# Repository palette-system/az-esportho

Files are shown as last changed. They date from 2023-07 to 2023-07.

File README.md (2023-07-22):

# AZ-ESPortho

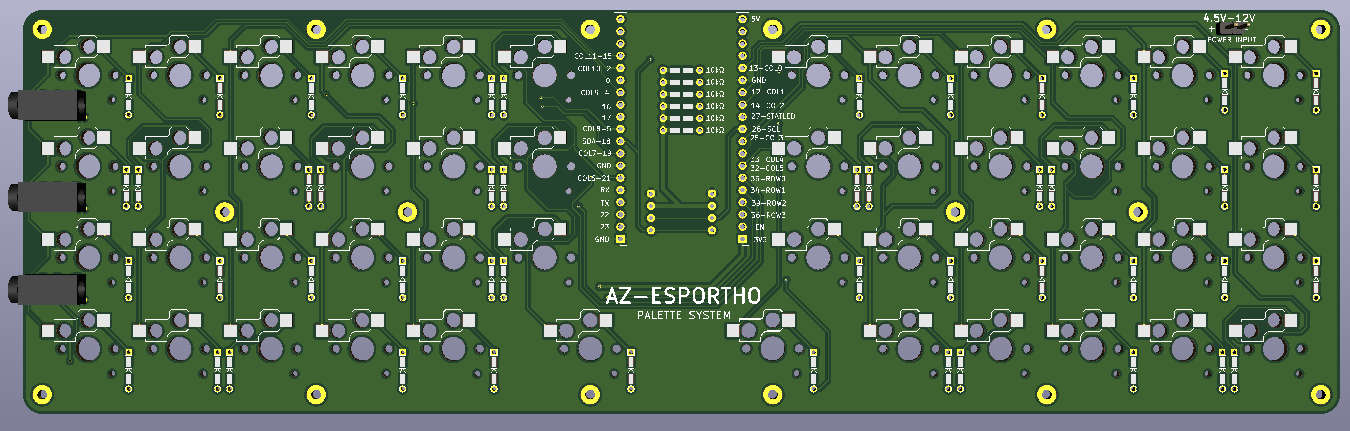
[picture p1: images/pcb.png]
pcb

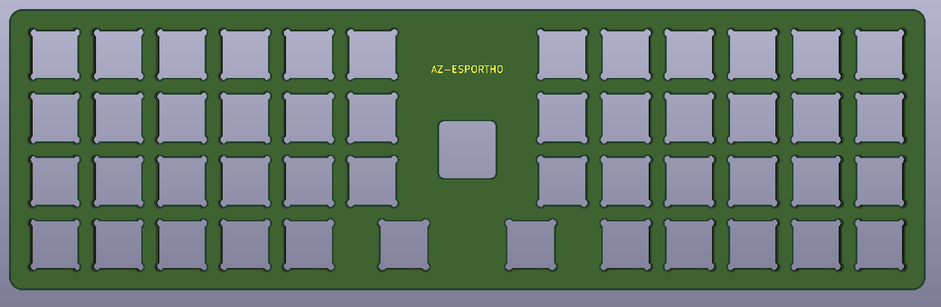
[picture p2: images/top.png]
top

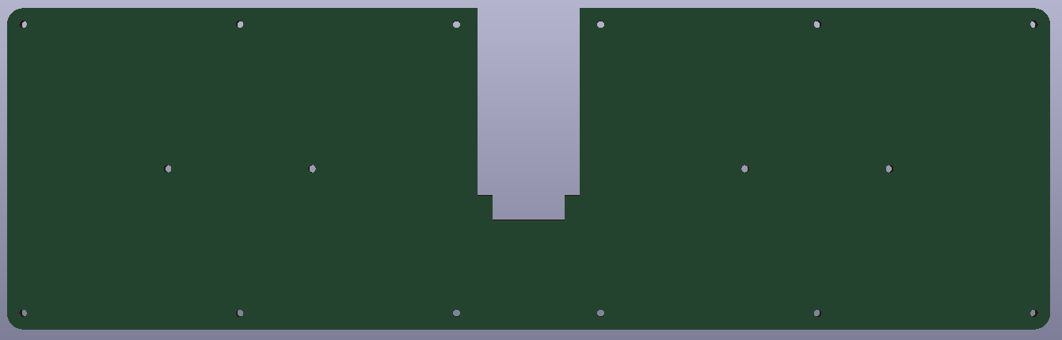
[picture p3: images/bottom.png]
bottom


## 情報
COL ピン
```
13,12,14,25,33,32,21,19,5,4,2,15
```
<br><br>

ROW ピン
```
35,34,39,36
```
<br><br>

I2C ピン
```
SDA=18 , SCL=26
```
<br><br>

KLE
```
["","","","","","",{x:2},"","","","","",""],
["","","","","","",{x:2},"","","","","",""],
["","","","","","",{x:2},"","","","","",""],
["","","","","",{w:2},"",{w:2},"","","","","",""]
```
<br><br>

## ライセンス
MIDライセンスにてPCBデータプレートデータを公開します。<br>
個人利用、商用利用自由に使用して頂いて大丈夫です。<br>
パレットシステムの名前とこのリポジトリのリンクを必ず明記して下さい。<br>
パレットシステムはこのデータを利用して起こったいかなる被害、問題にも責任を負いかねます。<br>

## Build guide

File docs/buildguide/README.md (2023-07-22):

# ビルドガイド

## １．用意が必要な物

| 名前 | 詳細 | 個数 |
| --- | --- | --- |
| ESP32開発ボード | <a href="https://akizukidenshi.com/catalog/g/gM-15673/" target="_blank">秋月電子リンク</a> | 1 |
| TRRSジャック | PJ320A（無くても良い） | 3 |
| ダイオード | SDM、DIP両方対応しています | 48 |
| Choc スイッチソケット | 　 | 48 |
| Choc スイッチ | V1、V2両方対応しています | 48 |
| キーキャップ | スイッチに対応したキャップ | 48 |
<br><br>

## ２．入っている物
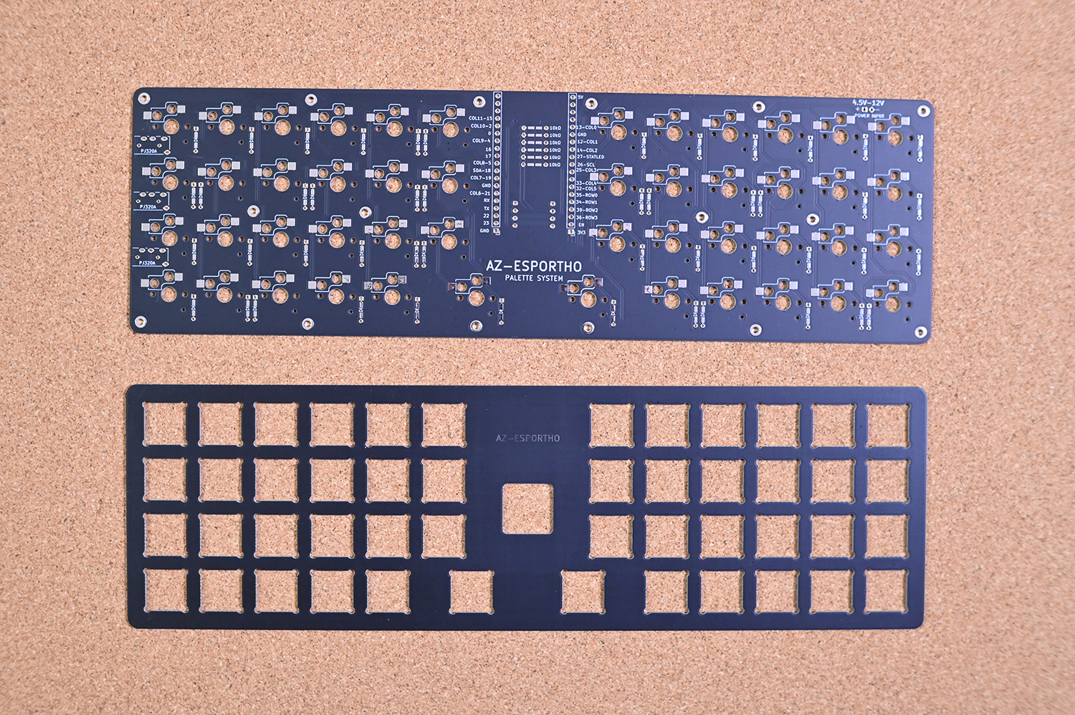
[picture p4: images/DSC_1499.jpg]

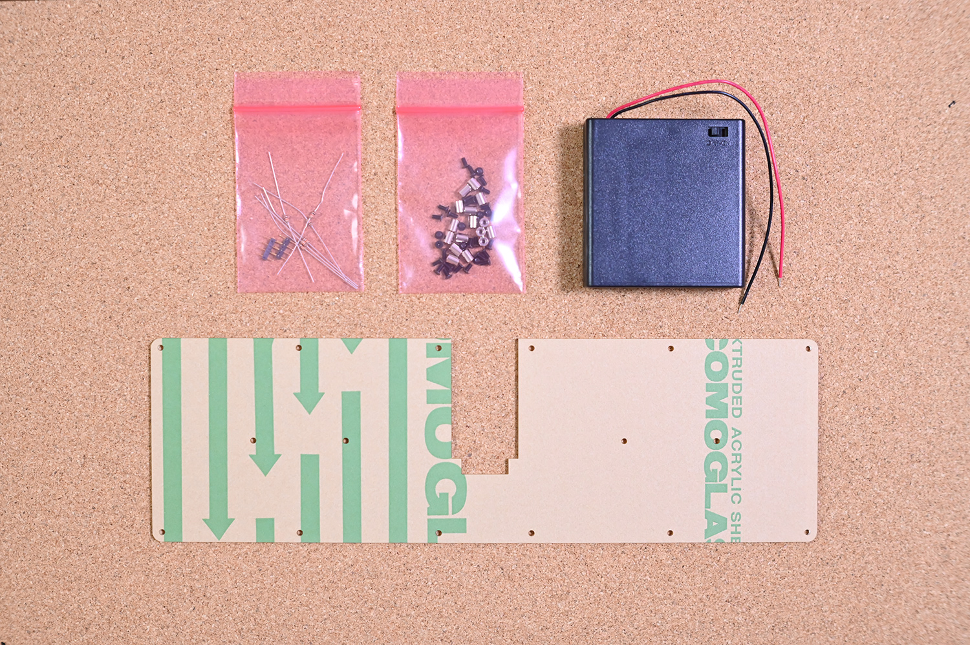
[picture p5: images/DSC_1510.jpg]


| 名前 | 詳細 | 個数 |
| --- | --- | --- |
| PCB | 　 | 1 |
| トッププレート | 　 | 1 |
| ボトムプレート | 透明 2mm厚 | 1 |
| コンスル― | 4ピン | 2 |
| 抵抗 | DIP 10kΩ | 6 |
| 電池ボックス | 単３ × ４本用 | 1 |
| 黒ネジ | M2 4mm | 32 |
| スペーサー | M2 5mm | 16 |
<br><br>

## ３．ダイオードのはんだ付け
裏面に48か所ダイオードがあるので写真の向きを参考にはんだ付けします。<br>
DIPをはんだ付けする場合は表面の出っ張りができないように注意して下さい。
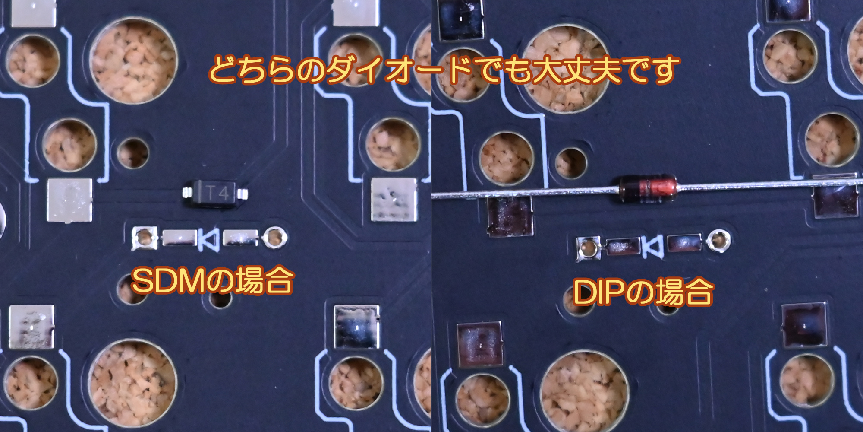
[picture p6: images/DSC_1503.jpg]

<br><br>

## ４．Chocスイッチのソケットはんだ付け
裏面に48か所あるので、写真を参考にはんだ付けします。
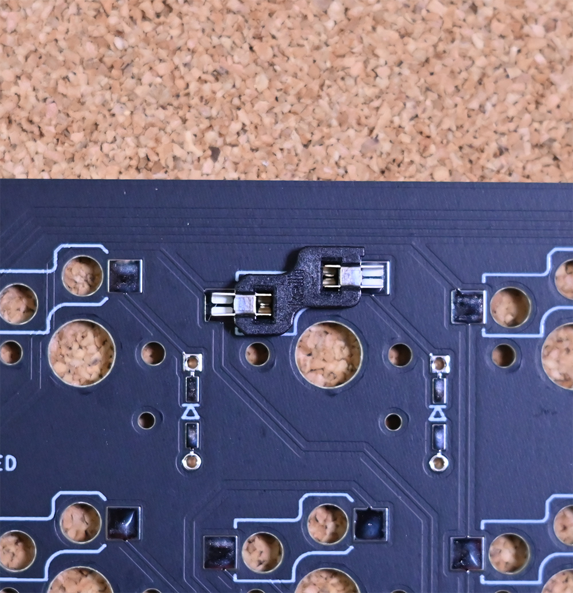
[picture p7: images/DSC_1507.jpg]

<br><br>

## ５．抵抗のはんだ付け
裏面に6ヶ所抵抗があるので写真を参考にはんだ付けします。<br>
表面の出っ張りができないように注意して下さい。
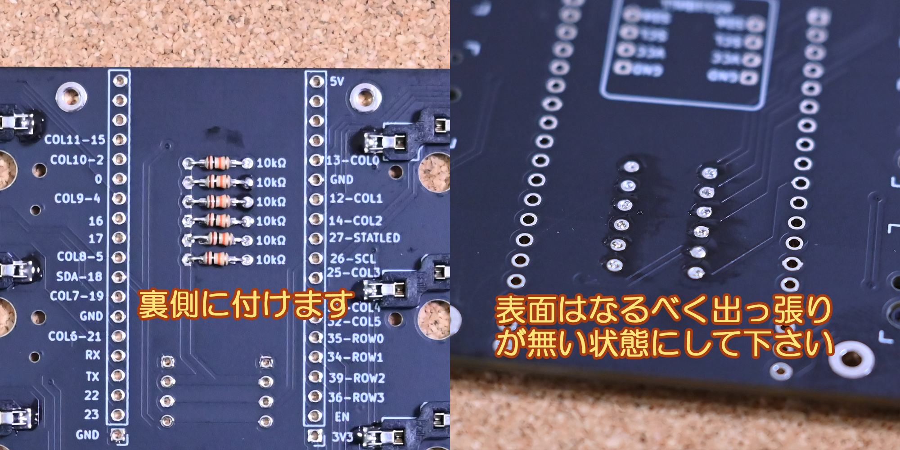
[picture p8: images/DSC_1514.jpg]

<br><br>

## ６．TRRSジャックのはんだ付け
裏面左端にTRRSが3ヶ所あります。<br>
はんだ付け前に足をカットして出っ張りが無いようにはんだ付けします。
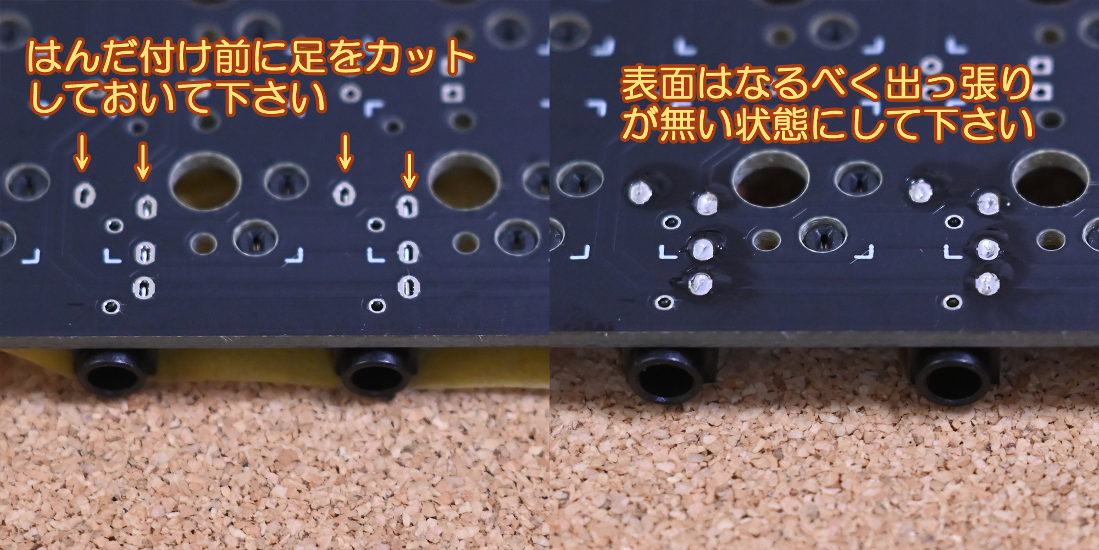
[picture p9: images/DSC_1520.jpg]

<br><br>

## ７．ESP32開発ボードの足をカット
他のパーツ同様表面に出っ張りができないようにはんだ付け前に足をカットします
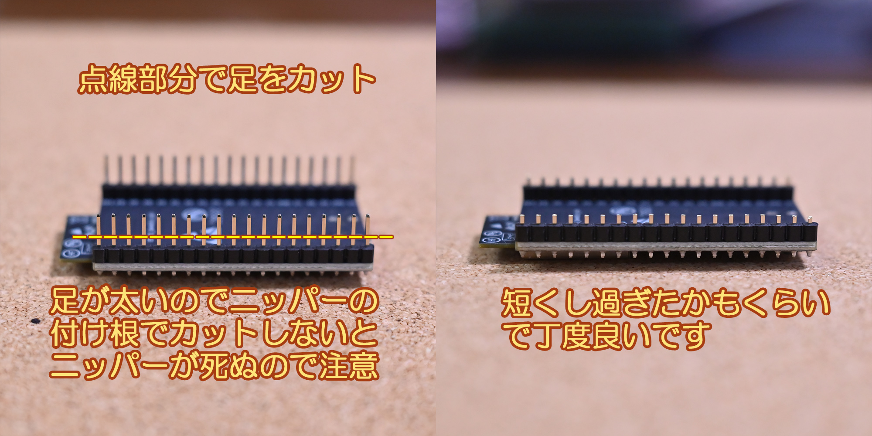
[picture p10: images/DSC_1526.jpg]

<br><br>

## ８．ESP32開発ボードのはんだ付け
裏面からUSBジャックが上に来るように差し込んで表面をはんだ付けします。
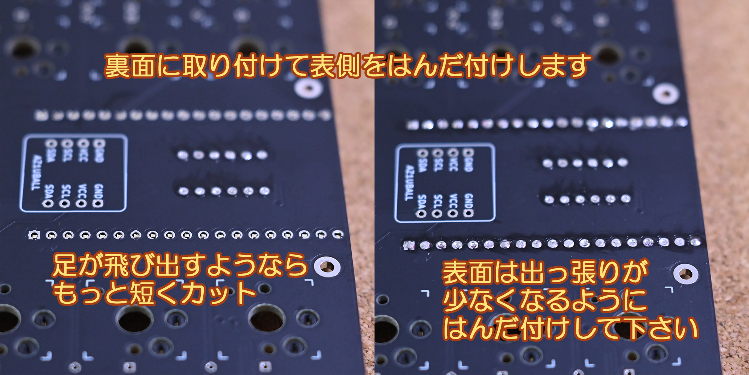
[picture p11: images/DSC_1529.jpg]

<br><br>

## ９．スペーサーの取り付け
表面からネジを差し込み裏をスペーサーで固定します。<br>
全部で16か所あるので全て固定します。
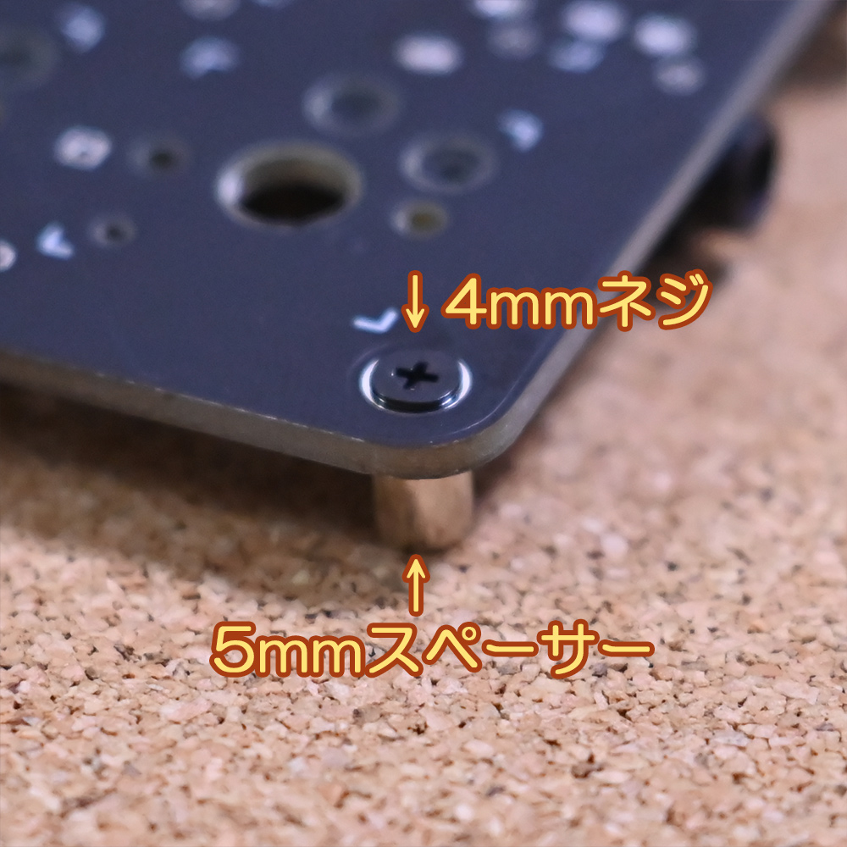
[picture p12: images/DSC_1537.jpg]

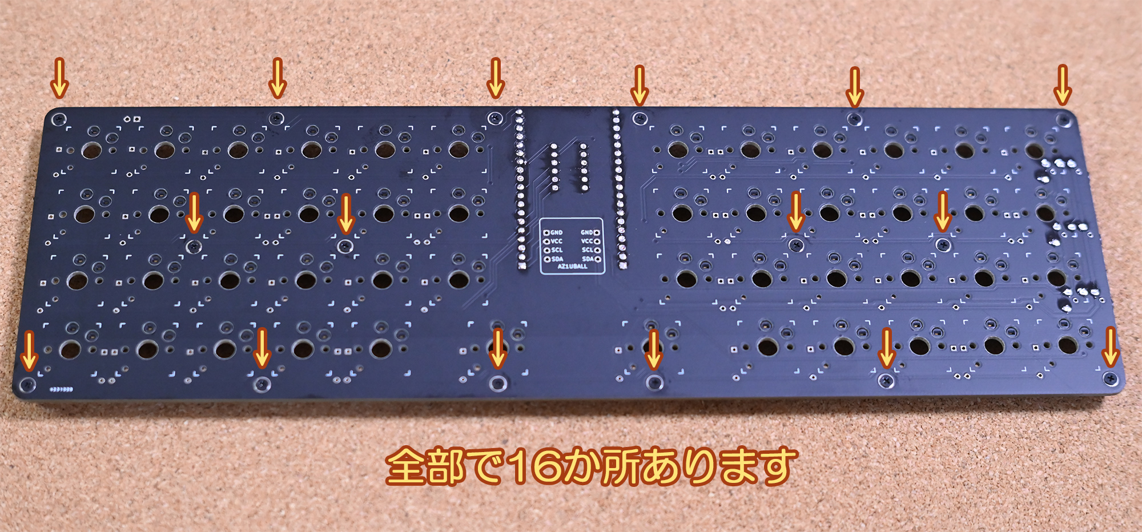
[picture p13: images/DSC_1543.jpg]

<br><br>

## １０．電池ボックスのはんだ付け
裏面右上に電源用の端子があるので＋－間違えないようはんだ付けします。
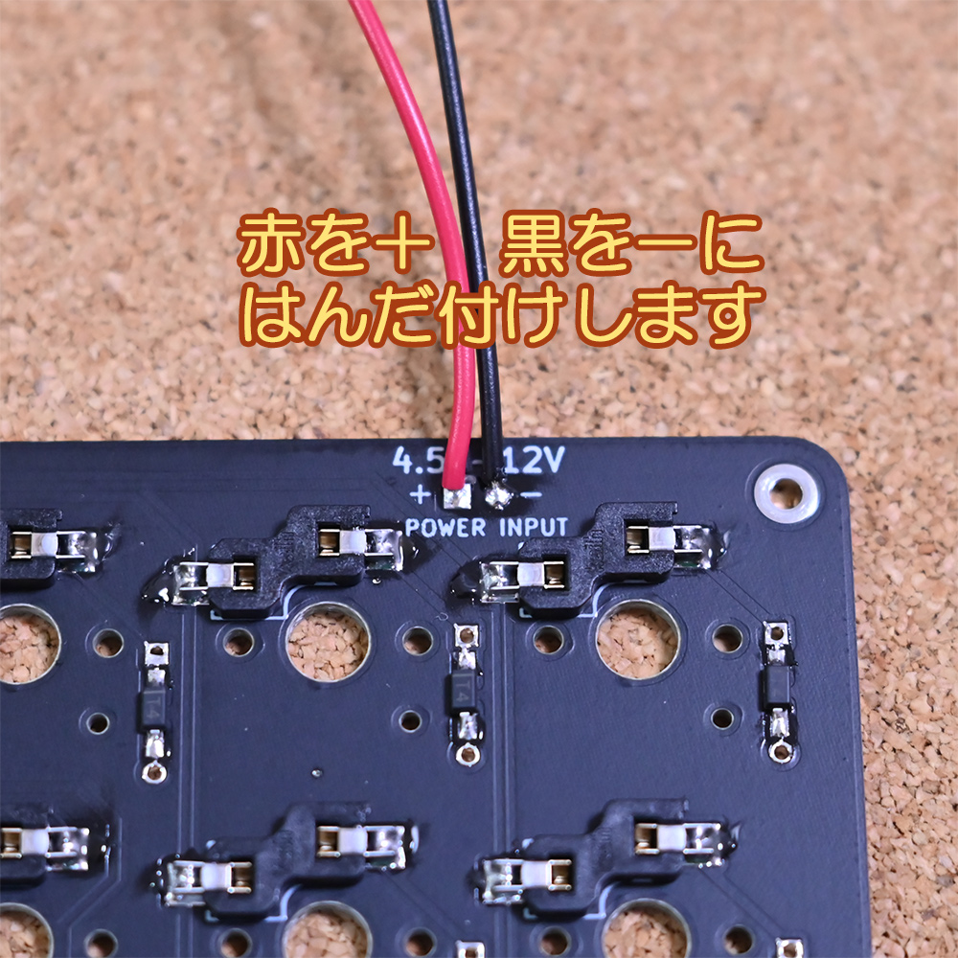
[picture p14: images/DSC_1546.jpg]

<br><br>

## １１．ボトムプレートの固定
ボトムプレートの保護シートをはがし、裏面に乗せます。
4mmネジで16か所固定します。
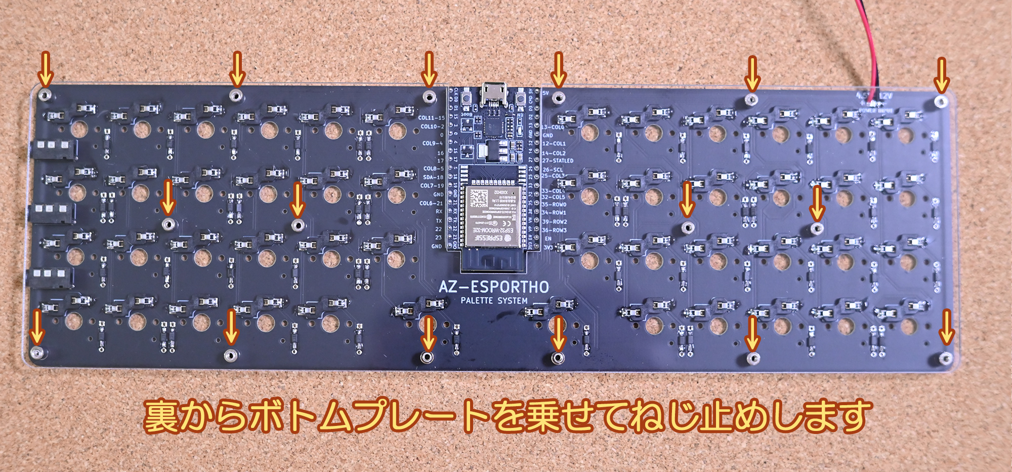
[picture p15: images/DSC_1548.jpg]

<br><br>

## １２．トッププレートにスイッチをはめ込む
トッププレートに使用するスイッチをはめ込んで下さい。<br>
この時PCBのスイッチソケットの向きを確認しながらスイッチの向きに気を付けて下さい。
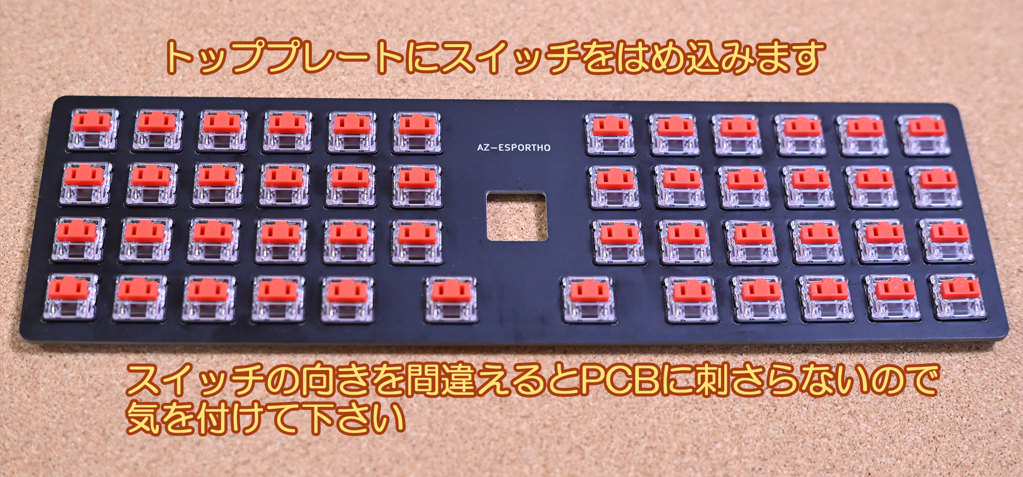
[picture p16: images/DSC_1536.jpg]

<br><br>

## １３．トッププレートごとPCBにスイッチをはめ込む
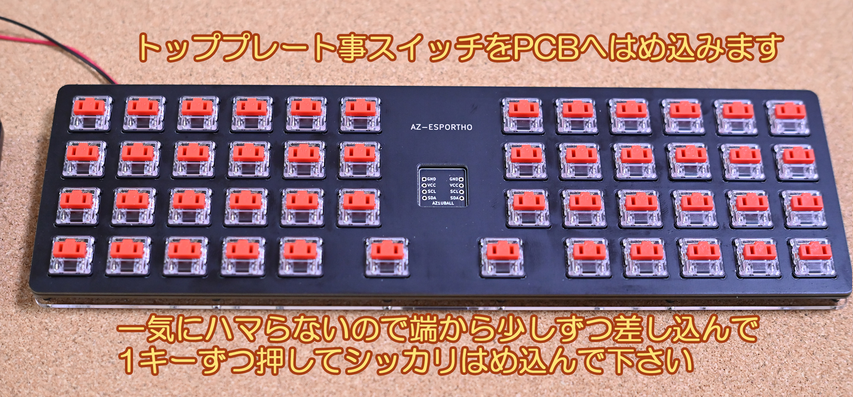
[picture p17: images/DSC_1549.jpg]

<br><br>

## １４．AZ1UBALLの取り付け
表面から4ピンコンスル―を差し込み、その上からAZ1UBALLを差し込んで下さい。
AZ1UBALLの組み立て方については <a href="https://github.com/palette-system/az1uball#%E7%B5%84%E3%81%BF%E7%AB%8B%E3%81%A6%E6%96%B9" target="_blank">こちら</a> を参照してください。
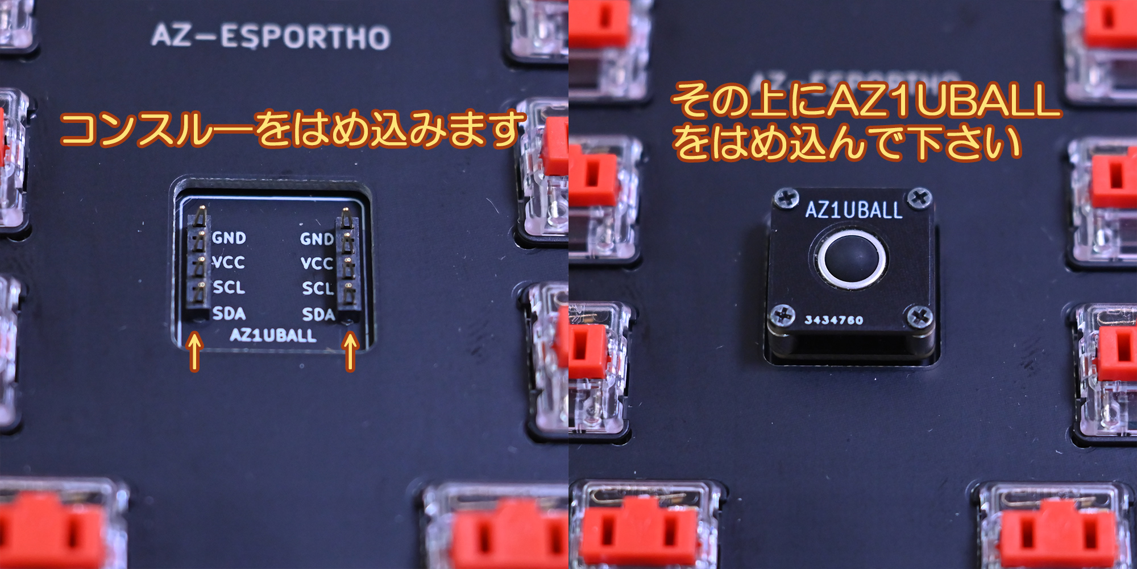
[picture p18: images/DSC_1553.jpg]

<br><br>

## １５．完成！
お疲れさまでした。これで完成です！<br>
あとはお好みのキャップを差し込んで下さい。
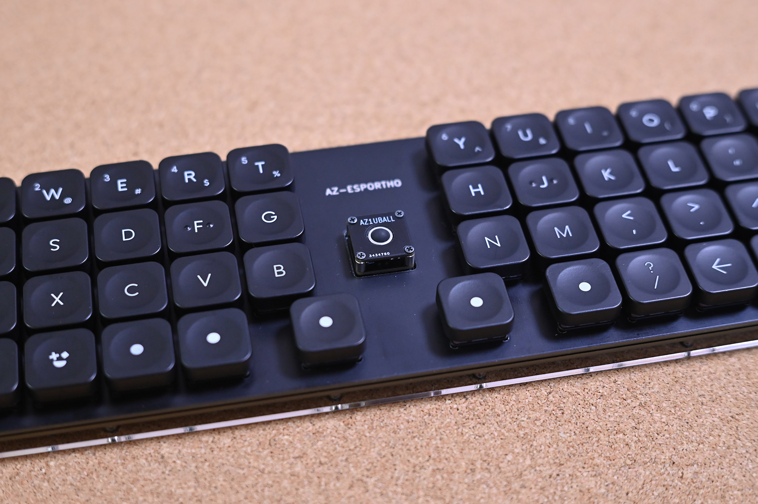
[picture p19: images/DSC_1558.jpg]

<br><br>

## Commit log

2023-07-06 add pcb
    [az-esportho_1.kicad_pcb, az-esportho_1_top.kicad_pcb]
2023-07-14 update pcb
    [az-esportho_1.kicad_pcb, az-esportho_2.kicad_pcb, az-esportho_2_bottom.kicad_pcb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]
